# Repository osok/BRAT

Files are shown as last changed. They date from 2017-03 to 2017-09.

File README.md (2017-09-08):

Table of Contents

- [Description](#description)
- [Key components](#key-components)
- [Schematics](#schematics)
- [Board Fabrication](#board-fabrication)
- [Parts list](#parts-list)
- [How to build the Board](#how-to-build-the-board)
- [Where to buy](#where-to-buy)
- [References](#references)
- [BRAT-GUI](#brat-gui)
- [How to use](#how-to-use)

# Description
BRAT or Badge Reader Active Tap, allows you to either install this implant into an HID Prox or iClass 
Reader inline between the reader and server.  It captures the bits from the Data0 and Data1 line and 
decodes the Wiegand protocol.  It stores the value on its file system and writes the bits back out to the 
server.

The Device has a built in Access Point and web server.  You can connect to the Access Point with and 
device such as a smart phone or computer.  You can interact with the device through its web page.  The 
default address is http://192.168.4.1/view. This provides list of previous cards that have been used on 
the reader.

The data stored is

* Card Hex	
* Facility Code	
* Card Number	
* Raw Bits

The Card Hex is a URL link to replay the card to the reader.

Optionally you can connect the BRAT-GUI on the BRAT-RPi device, which is designed to allow printing of 
the card with a proxmark3.

# Key components
The BRAT implant is built using the node mcu V 0.9.  The Node MCU leverages the ESP 8266 SoC to provide
a WiFi Access Point, 1 MB code and 3 MB Flash for storage, two interrupts and a number of GPIO pins.

The node mcu provides a 5V regulator and programming circuits for the ESP 8266 12. 

The AP default name iPhone-BRAT, which can be changed at compile time.
 
On the BRAT there is a 3V3 to 5V logic converter.  This jumps the 3V3 logic signal that is put out by the 
ESP, to 5V which is required to drive the signal to the server.
There is a 5V Regulator that takes the line power from the server to the reader, which is between 12V 
and 24V and drops it to 5V.
There are two 10 uF capacitors to smooth the power out.
The main board must be fabricated, see below for more information on that. 

# Schematics
I used Eagle CAD to design the circuit and board.
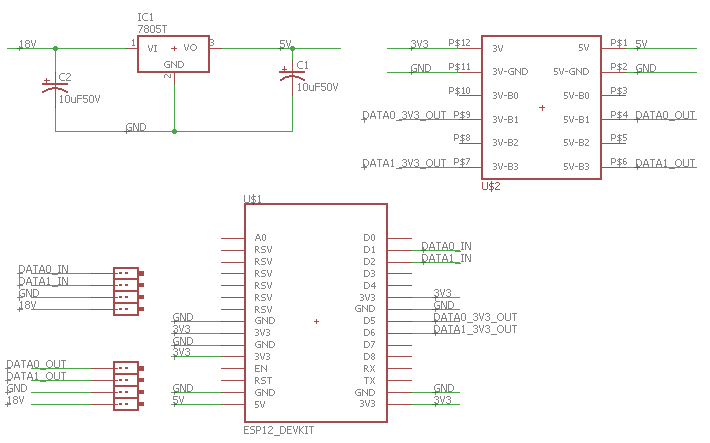
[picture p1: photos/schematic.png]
 

# Board Fabrication
When I fabricate my final boards I use [OSH Park](http://www.oshpark.com).  You will have to purchase 
three boards minimum for a total cost of $21.85 USD.

Front:<br>
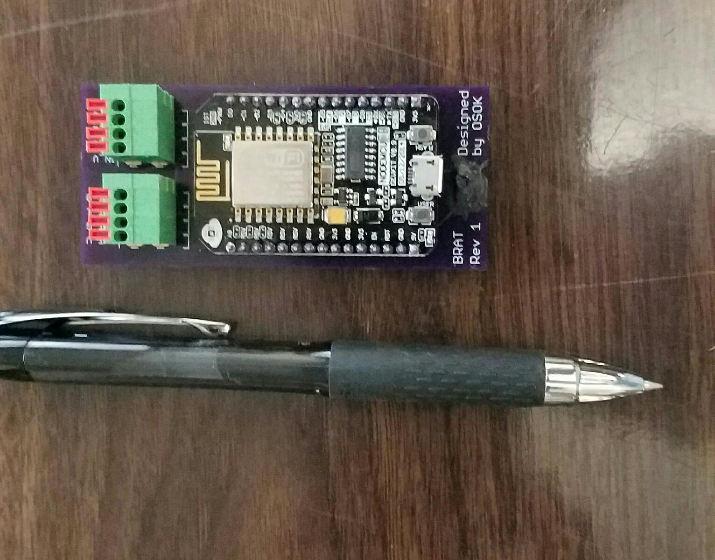
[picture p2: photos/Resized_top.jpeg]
 

Back:<br>
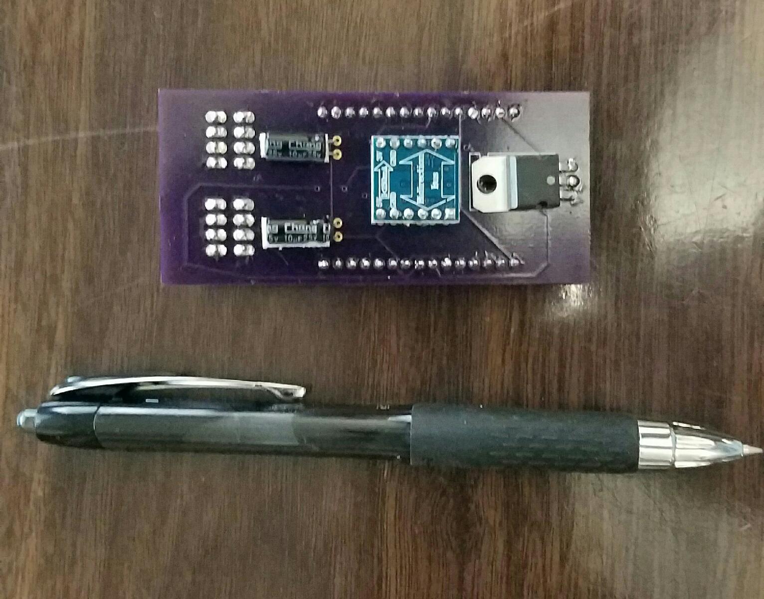
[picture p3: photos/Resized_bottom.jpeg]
 

# Parts list
So the cost individual cost is ~$24, depends on quantity and shipping.
* Node MCU $9
* Capacitors $1
* Level Converter $2
* Connectors $4
* Board $8

There are a number of different Logic converters out there.  Some simply move where the V_high/GND and V_low/GND are located, which makes them not compatable with this board, and others simply dont respond as they should.  Below are some examples:

 

I have found that even if you pay close attention to the ads on amazon and eBay, an only order the ones witht he double arrow on the back, some times they still send you other boards.

If you are only going to use this witht he Tastic, then you can forgo the Logic Level Converter.  Looking att he back side of the BRAT card solder the data out pins from the 3.3v side to straight across to the 5V side.  Don't solder the top pin one is 3V3 nd the other is 5V. That would be bad.  But 4th pin down and the bottom (6th Pin down) on the left solder a wire to the coresponding pin on the other side.   Left 4th pin to right 4th pin, and Left 6th pin to right 6th pin.   

# How to build the Board

https://youtu.be/rFhIB0w98co

# Where to buy
* I used some quick release connectors which can be ordered at: 
https://www.pololu.com/product/2427.
* The node mcu can be ordered from eBay or amazon: https://www.amazon.com/Industry-Park-NodeMcu-Internet-Development/dp/B01MG1LEU2/
* There are 2 Electrolytic Capacitors of 10 uF and at least 25V, I'll be using 50V. I have these as part of a 
larger kit.
* The voltage regulator is a LM7805.  I picked up about 20 of them from eBay.
* The level converter can be found on amazon: https://www.amazon.com/gp/product/B0148BLZGE/
* Board : 

# References
There are sections of the code that were orginally developed by Francis Brown of Bishop Fox for the [Tastic RFID Thief]( 
https://www.bishopfox.com/resources/tools/rfid-hacking/attack-tools/).  The BRAT works great in the 
Tastic RFID Thief.  This adds the capability for the user to monitor the badges acquired and for others to 
use the BRAT-GUI and BRAT-RPi to write badges as the attacker collects them.

# BRAT-GUI
The BRAT GUI is a Raspberry Pi with touch screen and ProxMark, for full life cycle badge cloning.  Use the BRAT in the Tastic
and the BRAT GUI to print badges on the fly.  

https://github.com/osok/BRAT/tree/master/BRAT-RPi-3D

# How to use

Once the BRAT is installed and powered on, you can connect to the AP.  The SSID can be modified before the source is compiled and loaded.  The password is also confgurable.  Based on what SSID / Password you used when compiling the source, will determine how to connect.

Once your mobile device is connected, you can use a browser to visit: http://192.168.4.2/view

You'll see the hex code with a link, Facility Code, Badge ID, and the raw bits.

Clicking the link with the hex code for a badge will replay the bits on the wire.  
So if this is installed as an implant you can replay cards that have been used since the implant was installed.

If the the device is being used witht he Tastic, use the BRAT-GUI to grab the card data from the BRAT and create clones in realtime.

# License

Creative Commons Attribution 3.0 United States
https://creativecommons.org/licenses/by/3.0/us/

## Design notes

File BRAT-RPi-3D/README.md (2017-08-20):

# Description

This box works great with  
* RPI 3 : https://www.adafruit.com/product/3055
* Pi foundation Display 7" Touch screen ($79): https://www.adafruit.com/product/2718
* Proxmark3 Easy ($88): https://www.ebay.com/i/262955750782?chn=ps&dispItem=1
* If you do not have a 3D printer all three parts costs about $80 - $120 on 3D hubs : https://www.3dhubs.com/ 
* Battery Pack ($39) : http://www.bestbuy.com/site/mycharge-razormax-portable-power-bank-black/6330174.p?skuId=6330174 :  I took it out of the case.  Using this style battery means longer life and easy to recharge.

See [RPI-GUI](https://github.com/osok/BRAT/tree/master/BRAT-GUI) for instructions on loading the software including the Ubuntu Mate.

# Assembly

TODO : Create video 

# License

Creative Commons Attribution 3.0 United States
https://creativecommons.org/licenses/by/3.0/us/

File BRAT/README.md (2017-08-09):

# Arduino Setup

Review instructions here for how to add the ESP 8266 boards to the Arduino IDE: https://github.com/esp8266/Arduino

# Config.h
Change the name of Config-Example.h to Config.h

You may want to pdate the SSID and the password for te Access Point so that others cannot connect as easily.  

# How to install software

Youtube video: https://youtu.be/guUEqy8e27w

Notes from the video
 
> You will need to code the GitHub Repo.
> https://github.com/osok/BRAT
> 
> In order to compile this You will need Ardunio IDE Installed.
> 
> Next you will need to install the NodeMCU Board.
> 
> Once you add the ESP 8266 board : http://arduino.esp8266.com/stable/package_esp8266com_index.json
> 
> Then restart the IDE.
> 
> Then goto tools > Boards > Board Manager and install
> 
> Then Select the Generic ESP8266
> 
> Then change to the Flash size to 4M (1M)
> 
> Then plug your BRAT Into the micro sd, selectt he port.  
> Press and hold the flash button while you plug the cable in.
> After 5 seconds you can release the button, it is now ready to be programmed.
>  
> Then you need to copy the Config-Example.h to Config.h
> In the Config.h Change the SSID and the password.
> 
> Then save and upload.  It will compile first.
> Then upload.
> Then success!!!

# License

Creative Commons Attribution 3.0 United States
https://creativecommons.org/licenses/by/3.0/us/

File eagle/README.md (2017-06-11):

Fabrication can be done at OSHPark : https://www.oshpark.com/

Link to the board on OSHPark : https://www.oshpark.com/shared_projects/jjDDSjZS

Link to Order the board : 


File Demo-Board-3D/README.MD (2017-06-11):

I used these to construct the demo board.
Mounting Clamps for 
* the BRAT
* Tastic control board 
* LCD Screen

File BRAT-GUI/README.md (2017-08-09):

# Description
BRAT-GUI is used on the BRAT-RPi to read the list of Hex Card values from the BRAT.  It is a java application cmpiled into a self executing JAR 

# Building the BRAT-GUI and BRAT-RPi

## BRAT-RPi

It's easiest to connect the RPi to a keyboard and mouse, while doing the set up.  You can use a HDMI monitor or the 7" Touch screen.

1. Install Ubunutu Mate : Follow instructions here https://ubuntu-mate.org/
2. Update the Ubuntu
```
sudo apt-get update
sudo apt-get upgrade
```
3. Install Proxmark3 for Ubuntu : Follow instructions here  https://github.com/Proxmark/proxmark3/wiki/Ubuntu-Linux
4. Install Java 8 to Ubuntu
```
sudo apt-get install openjdk-8-jdk
```

## BRAT-GUI
1. Download the BRAT-GUI.jar : https://github.com/osok/BRAT/tree/master/BRAT-GUI/dist
2. Download run.sh from the dist directory and place it in the same directory as the BRAT-GUI.jar
3. change the permissions on the run.sh file
```
chmod 700 run.sh
```
4. Download the lua script write_hid.lua and place it in the proxmark3/client/scripts directory : https://github.com/osok/BRAT/tree/master/proxmark3-scripts

# Operation

1. with the BRAT turned running
2. turn on the BRAT-GUI
3. open a terminal window and run proxmark client
```
sudo ./promark3 /dev/ttyACM0
```
4. run the run.sh
5. if you changed the IP address of the ESP (you would know it if you did), you can configure the Server IP in the configuration screen.
6. Press the Read Hex Codes
7. Select a Hex code to write_hid
8. Press write Hex Codes
9. Press the copy button
10. make sure there isa T5557 card in the card slot on the BRAT-RPi case
11. copy the contents of te clip board into the proxmark client terminal and hit enter

That's it.

# License

Creative Commons Attribution 3.0 United States
https://creativecommons.org/licenses/by/3.0/us/

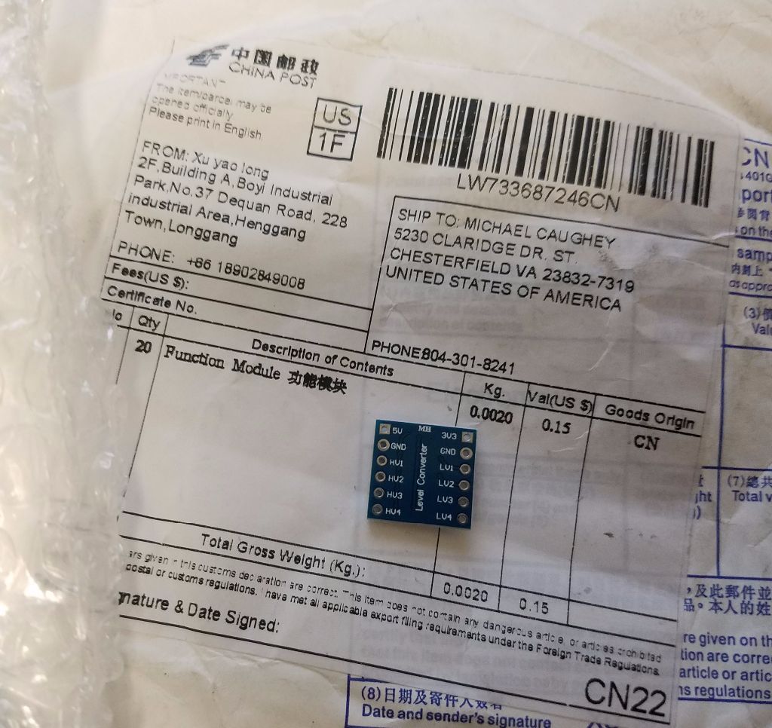
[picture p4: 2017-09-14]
photos/RtnDownloadFile.png

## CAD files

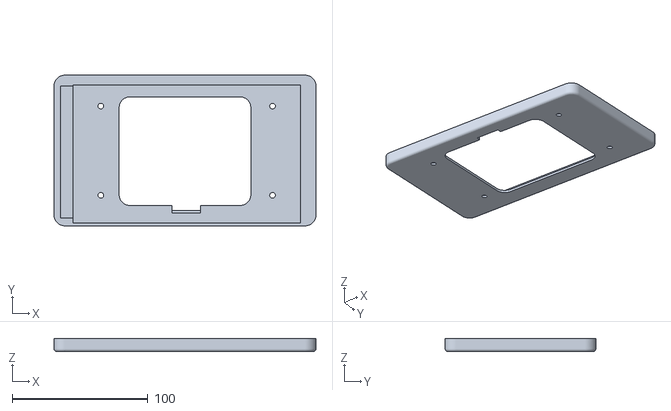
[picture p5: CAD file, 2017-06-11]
BRAT-RPi-3D/front.stl
193.0 x 111.0 x 9.60

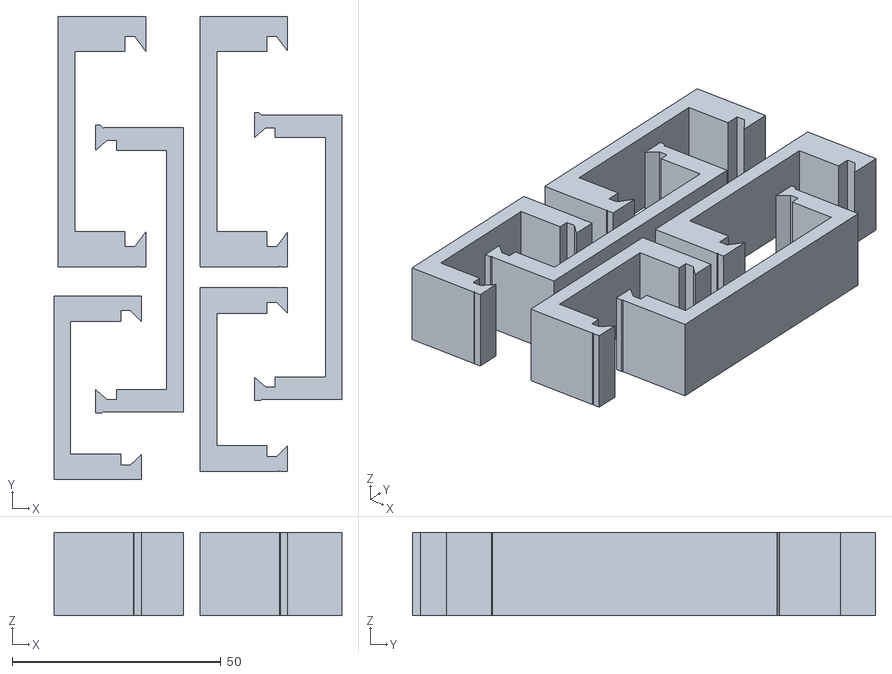
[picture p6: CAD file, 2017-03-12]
Demo-Board-3D/clamps.stl
69.0 x 111.0 x 20.0

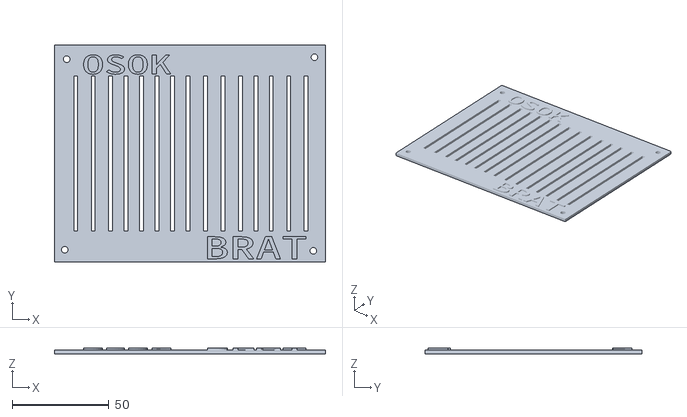
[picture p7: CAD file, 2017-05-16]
BRAT-RPi-3D/lid.stl
140.0 x 112.0 x 3.00

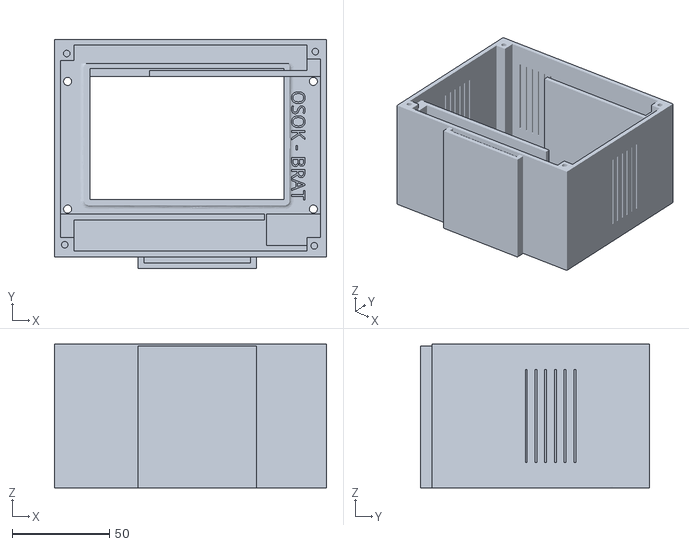
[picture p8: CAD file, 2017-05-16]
BRAT-RPi-3D/case.stl
140.0 x 118.0 x 74.0

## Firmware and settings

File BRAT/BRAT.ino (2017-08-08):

/**
 * BRAT.ino - Badge Reader Active Tap - is designed to
 *                connect to the Data0 & Data1 lines inside of a Wiegand
 *                based card reader.  It will store the card data on the 
 *                file system of an ESP8266-12.  The device sets up
 *                an Access Point that once connected to, presents
 *                a web page.  This web page shows card data info, and allows
 *                replay directly into the card reader.  A proxmark device
 *                can be used to program the card data onto a new card.
 *                The web server also provides a page of Hex vaules used
 *                by the BRAT RPi app. 
 *                
 * When I orginally set out to bypass the HID Prox devices, I did a lot of research        
 * I came along the Tastic RFID Reader by Bishop Fox, 
 * https://www.bishopfox.com/resources/tools/rfid-hacking/attack-tools/
 * After building a Tastic Reader I got the   idea that I could some how wirelessly 
 * send the card data to someon that could  then wirte a card for immediate use.
 * 
 * The portions of this code that read the signal from the line 
 * and decode the bits into FC and Card Num are the same
 * as what was coded in the Tastic thief.
 * 
 * The follwoing code is orginal to the BRAT
 *   - AP configuration
 *   - Web Server
 *   - Writing to another pair of pins are all orgiinal
 *   - the Trace logic for debugging
 *             
 * Created by osok
 * github https://github.com/osok/BRAT
 */


#include "Config.h"
#include <string.h>
#include <ESP8266WiFi.h>
#include <WiFiClient.h> 
#include <ESP8266WebServer.h>
#include <FS.h>
//#include <ArduinoOTA.h>

#define HOSTNAME "ESP8266-OTA-"

ESP8266WebServer server(80);

#define MAX_BITS 100                 // max number of bits 
#define WEIGAND_WAIT_TIME  3000      // time to wait for another weigand pulse.  


char* dataFile = "cards.htm"; // file to save card ids to
char* hexFile = "card-hex.htm"; // only the card hex is written to this file, one per line

unsigned char databits[MAX_BITS];    // stores all of the data bits
volatile unsigned int bitCount = 0;
unsigned char flagDone;          // goes low when data is currently being captured
unsigned int weigand_counter;        // countdown until we assume there are no more bits

volatile unsigned long facilityCode=0;        // decoded facility code
volatile unsigned long cardCode=0;            // decoded card code

// Breaking up card value into 2 chunks to create 10 char HEX value
volatile unsigned long bitHolder1 = 0;
volatile unsigned long bitHolder2 = 0;
volatile unsigned long cardChunk1 = 0;
volatile unsigned long cardChunk2 = 0;


#define DATA0_IN 5
#define DATA1_IN 4
#define DATA0_OUT 14
#define DATA1_OUT 12

/**
 * These variables are for the writing of the 
 * Bits to the bade reader 
 */
////These were based on timming from ebuging code
//#define SHORT_TIME 7  // 50 microseconds
////#define LONG_TIME 166 // 1 millisecond
//#define LONG_TIME 151 // 1 millisecond (minus overhead for wire writes)
//
// These are based on timing as seen by a logic analyzer
#define SHORT_TIME 655  // 50 microseconds
#define LONG_TIME 27146 // 1 millisecond (Takes into account over head other than the delay loop)
//#define LONG_TIME 16000 // 

int bitcnt1;
int bitcnt2;

unsigned long startTime;
unsigned long shortTime[80];
unsigned long longTime[80];
boolean isAOne[80];
boolean bitUsed[80];
int bitCountToWrite;
unsigned long endTime;


boolean isWriting = false;

///////////////////////////////////////////////////////
// Process interrupts

// interrupt that happens when INTO goes low (0 bit)
//[Copied from the Tastic RFID Thief]
void ISR_INT0()
{
 if(!isWriting){
//  Serial.print("0");
    bitCount++;
    flagDone = 0;
    
    if(bitCount < 23) {
        bitHolder1 = bitHolder1 << 1;
        bitcnt1++;
    }
    else {
        bitHolder2 = bitHolder2 << 1;
        bitcnt2++;
    }
      
    weigand_counter = WEIGAND_WAIT_TIME;  
 }
}

// interrupt that happens when INT1 goes low (1 bit)
//[Copied from the Tastic RFID Thief]
void ISR_INT1()
{
  if(!isWriting){
  //  Serial.print("1");
    databits[bitCount] = 1;
    bitCount++;
    flagDone = 0;
    
     if(bitCount < 23) {
        bitHolder1 = bitHolder1 << 1;
        bitHolder1 |= 1;
        bitcnt1++;
     }
     else {
       bitHolder2 = bitHolder2 << 1;
       bitHolder2 |= 1;
        bitcnt2++;
     }
    
    weigand_counter = WEIGAND_WAIT_TIME;  
  }
}

String getContentType(String filename){
  if(server.hasArg("download")) return "application/octet-stream";
  else if(filename.endsWith(".htm")) return "text/html";
  else if(filename.endsWith(".html")) return "text/html";
  else if(filename.endsWith(".css")) return "text/css";
  else if(filename.endsWith(".js")) return "application/javascript";
  else if(filename.endsWith(".png")) return "image/png";
  else if(filename.endsWith(".gif")) return "image/gif";
  else if(filename.endsWith(".jpg")) return "image/jpeg";
  else if(filename.endsWith(".ico")) return "image/x-icon";
  else if(filename.endsWith(".xml")) return "text/xml";
  else if(filename.endsWith(".pdf")) return "application/x-pdf";
  else if(filename.endsWith(".zip")) return "application/x-zip";
  else if(filename.endsWith(".gz")) return "application/x-gzip";
  return "text/plain";
}

bool handleFileRead(String path){
  Serial.println("handleFileRead: " + path);
  if(path.endsWith("/")) path += "index.htm";
  String contentType = getContentType(path);
  String pathWithGz = path + ".gz";
  if(SPIFFS.exists(pathWithGz) || SPIFFS.exists(path)){
    if(SPIFFS.exists(pathWithGz))
      path += ".gz";
    File file = SPIFFS.open(path, "r");
    size_t sent = server.streamFile(file, contentType);
    file.close();
    return true;
  }
  return false;
}

void handleCard() {
  handleFileRead(dataFile);
}
void handleCardHex() {
  handleFileRead(hexFile);
}


void handleClear() {
  SPIFFS.remove(dataFile);
  SPIFFS.remove(hexFile);
  server.send(200, "text/html", "<html><body>All Clear</body></html>");
}

void handleAccess() {
  unsigned long bitbuf1 = atol(server.arg("byte1").c_str());
  unsigned long  bitbuf2 = atol(server.arg("byte2").c_str());
  int bCnt1 = atol(server.arg("bitcnt1").c_str());
  int bCnt2 = atol(server.arg("bitcnt2").c_str());
  Serial.print("byte1=");
  Serial.println(bitbuf1);
  Serial.print("byte2=");
  Serial.println(bitbuf2);
  Serial.print("bits1=");
  Serial.println(bitbuf1,BIN);
  Serial.print("bits2=");
  Serial.println(bitbuf2, BIN);
  Serial.print("bCnt1=");
  Serial.println(bCnt1);
  Serial.print("bCnt2=");
  Serial.println(bCnt2);

   
  sendBadgeBits(bitbuf1,bitbuf2,bCnt1,bCnt2 );
  //printTimes();
  handleView();
}

void handleView() {
  //This is seperate in order to add eventual formatting around the card page
  server.send(200, "text/html", "<html><body><iframe src=\"/card\" frameborder=\"0\" scrolling=\"no\" width=\"100%\" height=\"100%\"></html>");
}

void setupForRFIDRead(){
  
  pinMode(DATA0_IN, INPUT_PULLUP);     
  pinMode(DATA1_IN, INPUT_PULLUP);   
  delay(500);  
  attachInterrupt(digitalPinToInterrupt(DATA0_IN), ISR_INT0, FALLING);  
  attachInterrupt(digitalPinToInterrupt(DATA1_IN), ISR_INT1, FALLING);
  Serial.println("Ready to read...");
}


void setupForRFIDWrite(){
  pinMode(DATA0_OUT, OUTPUT);     
  pinMode(DATA1_OUT, OUTPUT);    
  digitalWrite(DATA0_OUT, HIGH);
  digitalWrite(DATA1_OUT, HIGH);
  delay(500);
  Serial.println("Ready to write...");
}

void setup() {

  Serial.begin(115200);
  setupForRFIDRead();
  setupForRFIDWrite();
  
  Serial.println();
  Serial.print("Chip ID: 0x");
  Serial.println(ESP.getChipId(), HEX);
  Serial.println();
  String hostname(HOSTNAME);
  hostname += String(ESP.getChipId(), HEX);
  WiFi.hostname(hostname);
  Serial.println("Hostname: " + hostname);
 
  Serial.print("Configuring AP...");

  if (!SPIFFS.begin())
  {
    Serial.println("Failed to mount file system");
    return;
  }

  WiFi.softAP(ssid, password);

  IPAddress myIP = WiFi.softAPIP();
  Serial.print("IP address: ");
  Serial.println(myIP);
  server.on("/clear", handleClear);
  server.on("/view", handleView);
  server.on("/card", handleCard);
  server.on("/hex", handleCardHex);
  server.on("/access", handleAccess);
  server.begin();
  Serial.println("server started");

//  ArduinoOTA.setHostname((const char *)hostname.c_str());
//  ArduinoOTA.begin();

  weigand_counter = WEIGAND_WAIT_TIME;

}

void loop() {
  server.handleClient();
  yield();
//  ArduinoOTA.handle();
//  yield();
  
  // This waits to make sure that there have been no more data pulses before processing data
  if (!flagDone) {

    
    if (--weigand_counter == 0)
      flagDone = 1;  
  }
  
  // if we have bits and we the weigand counter went out
  if (bitCount > 0 && flagDone) {
//    Serial.print("Bitcount 1 = ");
//    Serial.println(bitcnt1);
//    Serial.print("Bitcount 2 = ");
//    Serial.println(bitcnt2);
    
    unsigned char i;

    //Write bits to the wire first thing in order to reduce delay
    sendBadgeBits(bitHolder1,bitHolder2,bitcnt1,bitcnt2 );
    
    getCardValues();
    getCardNumAndSiteCode();
       
    printBits();
    writeDataToFS();

     // cleanup and get ready for the next card
     bitCount = 0; facilityCode = 0; cardCode = 0;
     bitHolder1 = 0; bitHolder2 = 0;
     cardChunk1 = 0; cardChunk2 = 0;
     
     for (i=0; i<MAX_BITS; i++) 
     {
       databits[i] = 0;
     }

     bitcnt1 = 0;
     bitcnt2 = 0;
  }  
}
void printBits(){
      Serial.print(bitCount);
      Serial.print(" bit card. ");
      Serial.print("FC = ");
      Serial.print(facilityCode);
      Serial.print(", CC = ");
      Serial.print(cardCode);
      Serial.print(", 44bit HEX = ");
      Serial.print(cardChunk1, HEX);
      Serial.println(cardChunk2, HEX);
      
  }

  ///////////////////////////////////////////////////////
// SETUP function  [Copied from the Tastic RFID Thief]
void getCardNumAndSiteCode()
{
     unsigned char i;
  
    // we will decode the bits differently depending on how many bits we have
    // see www.pagemac.com/azure/data_formats.php for more info
    // also specifically: https://www.brivo.com/support/card-calculator
    switch (bitCount) {

      
    ///////////////////////////////////////
    // standard 26 bit format
    // facility code = bits 2 to 9  
    case 26:
      for (i=1; i<9; i++)
      {
         facilityCode <<=1;
         facilityCode |= databits[i];
      }
      
      // card code = bits 10 to 23
      for (i=9; i<25; i++)
      {
         cardCode <<=1;
         cardCode |= databits[i];
      }
      break;

    ///////////////////////////////////////
    // 33 bit HID Generic    
    case 33:  
      for (i=1; i<8; i++)
      {
         facilityCode <<=1;
         facilityCode |= databits[i];
      }
      
      // card code
      for (i=8; i<32; i++)
      {
         cardCode <<=1;
         cardCode |= databits[i];
      }    
      break;

    ///////////////////////////////////////
    // 34 bit HID Generic 
    case 34:  
      for (i=1; i<17; i++)
      {
         facilityCode <<=1;
         facilityCode |= databits[i];
      }
      
      // card code
      for (i=17; i<33; i++)
      {
         cardCode <<=1;
         cardCode |= databits[i];
      }    
      break;
 
    ///////////////////////////////////////
    // 35 bit HID Corporate 1000 format
    // facility code = bits 2 to 14     
    case 35:  
      for (i=2; i<14; i++)
      {
         facilityCode <<=1;
         facilityCode |= databits[i];
      }
      
      // card code = bits 15 to 34
      for (i=14; i<34; i++)
      {
         cardCode <<=1;
         cardCode |= databits[i];
      }    
      break;

    }
    return;
  
}


//////////////////////////////////////
// Function to append the card value (bitHolder1 and bitHolder2) to the necessary array then tranlate that to
// the two chunks for the card value that will be output
// [Copied from the Tastic RFID Thief]
void getCardValues() {
  switch (bitCount) {
    case 26:
        // Example of full card value
        // |>   preamble   <| |>   Actual card value   <|
        // 000000100000000001 11 111000100000100100111000
        // |> write to chunk1 <| |>  write to chunk2   <|
        
       for(int i = 19; i >= 0; i--) {
          if(i == 13 || i == 2){
            bitWrite(cardChunk1, i, 1); // Write preamble 1's to the 13th and 2nd bits
          }
          else if(i > 2) {
            bitWrite(cardChunk1, i, 0); // Write preamble 0's to all other bits above 1
          }
          else {
            bitWrite(cardChunk1, i, bitRead(bitHolder1, i + 20)); // Write remaining bits to cardChunk1 from bitHolder1
          }
          if(i < 20) {
            bitWrite(cardChunk2, i + 4, bitRead(bitHolder1, i)); // Write the remaining bits of bitHolder1 to cardChunk2
          }
          if(i < 4) {
            bitWrite(cardChunk2, i, bitRead(bitHolder2, i)); // Write the remaining bit of cardChunk2 with bitHolder2 bits
          }
        }
        break;

    case 27:
       for(int i = 19; i >= 0; i--) {
          if(i == 13 || i == 3){
            bitWrite(cardChunk1, i, 1);
          }
          else if(i > 3) {
            bitWrite(cardChunk1, i, 0);
          }
          else {
            bitWrite(cardChunk1, i, bitRead(bitHolder1, i + 19));
          }
          if(i < 19) {
            bitWrite(cardChunk2, i + 5, bitRead(bitHolder1, i));
          }
          if(i < 5) {
            bitWrite(cardChunk2, i, bitRead(bitHolder2, i));
          }
        }
        break;

    case 28:
       for(int i = 19; i >= 0; i--) {
          if(i == 13 || i == 4){
            bitWrite(cardChunk1, i, 1);
          }
          else if(i > 4) {
            bitWrite(cardChunk1, i, 0);
          }
          else {
            bitWrite(cardChunk1, i, bitRead(bitHolder1, i + 18));
          }
          if(i < 18) {
            bitWrite(cardChunk2, i + 6, bitRead(bitHolder1, i));
          }
          if(i < 6) {
            bitWrite(cardChunk2, i, bitRead(bitHolder2, i));
          }
        }
        break;

    case 29:
       for(int i = 19; i >= 0; i--) {
          if(i == 13 || i == 5){
            bitWrite(cardChunk1, i, 1);
          }
          else if(i > 5) {
            bitWrite(cardChunk1, i, 0);
          }
          else {
            bitWrite(cardChunk1, i, bitRead(bitHolder1, i + 17));
          }
          if(i < 17) {
            bitWrite(cardChunk2, i + 7, bitRead(bitHolder1, i));
          }
          if(i < 7) {
            bitWrite(cardChunk2, i, bitRead(bitHolder2, i));
          }
        }
        break;

    case 30:
       for(int i = 19; i >= 0; i--) {
          if(i == 13 || i == 6){
            bitWrite(cardChunk1, i, 1);
          }
          else if(i > 6) {
            bitWrite(cardChunk1, i, 0);
          }
          else {
            bitWrite(cardChunk1, i, bitRead(bitHolder1, i + 16));
          }
          if(i < 16) {
            bitWrite(cardChunk2, i + 8, bitRead(bitHolder1, i));
          }
          if(i < 8) {
            bitWrite(cardChunk2, i, bitRead(bitHolder2, i));
          }
        }
        break;

    case 31:
       for(int i = 19; i >= 0; i--) {
          if(i == 13 || i == 7){
            bitWrite(cardChunk1, i, 1);
          }
          else if(i > 7) {
            bitWrite(cardChunk1, i, 0);
          }
          else {
            bitWrite(cardChunk1, i, bitRead(bitHolder1, i + 15));
          }
          if(i < 15) {
            bitWrite(cardChunk2, i + 9, bitRead(bitHolder1, i));
          }
          if(i < 9) {
            bitWrite(cardChunk2, i, bitRead(bitHolder2, i));
          }
        }
        break;

    case 32:
       for(int i = 19; i >= 0; i--) {
          if(i == 13 || i == 8){
            bitWrite(cardChunk1, i, 1);
          }
          else if(i > 8) {
            bitWrite(cardChunk1, i, 0);
          }
          else {
            bitWrite(cardChunk1, i, bitRead(bitHolder1, i + 14));
          }
          if(i < 14) {
            bitWrite(cardChunk2, i + 10, bitRead(bitHolder1, i));
          }
          if(i < 10) {
            bitWrite(cardChunk2, i, bitRead(bitHolder2, i));
          }
        }
        break;

    case 33:
       for(int i = 19; i >= 0; i--) {
          if(i == 13 || i == 9){
            bitWrite(cardChunk1, i, 1);
          }
          else if(i > 9) {
            bitWrite(cardChunk1, i, 0);
          }
          else {
            bitWrite(cardChunk1, i, bitRead(bitHolder1, i + 13));
          }
          if(i < 13) {
            bitWrite(cardChunk2, i + 11, bitRead(bitHolder1, i));
          }
          if(i < 11) {
            bitWrite(cardChunk2, i, bitRead(bitHolder2, i));
          }
        }
        break;

    case 34:
       for(int i = 19; i >= 0; i--) {
          if(i == 13 || i == 10){
            bitWrite(cardChunk1, i, 1);
          }
          else if(i > 10) {
            bitWrite(cardChunk1, i, 0);
          }
          else {
            bitWrite(cardChunk1, i, bitRead(bitHolder1, i + 12));
          }
          if(i < 12) {
            bitWrite(cardChunk2, i + 12, bitRead(bitHolder1, i));
          }
          if(i < 12) {
            bitWrite(cardChunk2, i, bitRead(bitHolder2, i));
          }
        }
        break;

    case 35:        
       for(int i = 19; i >= 0; i--) {
          if(i == 13 || i == 11){
            bitWrite(cardChunk1, i, 1);
          }
          else if(i > 11) {
            bitWrite(cardChunk1, i, 0);
          }
          else {
            bitWrite(cardChunk1, i, bitRead(bitHolder1, i + 11));
          }
          if(i < 11) {
            bitWrite(cardChunk2, i + 13, bitRead(bitHolder1, i));
          }
          if(i < 13) {
            bitWrite(cardChunk2, i, bitRead(bitHolder2, i));
          }
        }
        break;

    case 36:
       for(int i = 19; i >= 0; i--) {
          if(i == 13 || i == 12){
            bitWrite(cardChunk1, i, 1);
          }
          else if(i > 12) {
            bitWrite(cardChunk1, i, 0);
          }
          else {
            bitWrite(cardChunk1, i, bitRead(bitHolder1, i + 10));
          }
          if(i < 10) {
            bitWrite(cardChunk2, i + 14, bitRead(bitHolder1, i));
          }
          if(i < 14) {
            bitWrite(cardChunk2, i, bitRead(bitHolder2, i));
          }
        }
        break;

    case 37:
       for(int i = 19; i >= 0; i--) {
          if(i == 13){
            bitWrite(cardChunk1, i, 0);
          }
          else {
            bitWrite(cardChunk1, i, bitRead(bitHolder1, i + 9));
          }
          if(i < 9) {
            bitWrite(cardChunk2, i + 15, bitRead(bitHolder1, i));
          }
          if(i < 15) {
            bitWrite(cardChunk2, i, bitRead(bitHolder2, i));
          }
        }
        break;
  }
  return;
}

/**
 * Used to write the stored badge bits to the wire 
 */
void sendBadgeBits(unsigned long bits1,unsigned long bits2, int bCnt1, int bCnt2){
  isWriting = true;
  setupForRFIDWrite();
  startTime = ESP.getCycleCount(); 
  unsigned long test = 0;
  unsigned long shiftedBits;
  int adjustment;
  bitCountToWrite = 0;
  
//  Setting up the first set of bits
//  Serial.println(bits1, BIN);
 
  for(int i=bCnt1-1;i >= 0; i--){
    if(i>23 ){
      shiftedBits = bits1 >> 24;
      adjustment = 24;
    }else if(i>15 ){
      shiftedBits = bits1 >> 16;
      adjustment = 16;
    }else if(i>7 ){
      shiftedBits = bits1 >> 8;
      adjustment = 8;
    }else {
      shiftedBits = bits1;
      adjustment = 0;
    }
    
    bitCountToWrite++;
    bitUsed[i+bCnt2] = true;
    test = 0;
    test = 1UL << (i-adjustment);
//    Serial.print("adjustment = ");
//    Serial.println(adjustment);
//    Serial.print("Test = ");
//    Serial.println(test, BIN);
    isAOne[i+bCnt2] = (shiftedBits & test);
    
//    Serial.print("Index = ");
//    Serial.println((i+bCnt2));
//    Serial.print("Bit = ");
//    Serial.println(isAOne[i+bCnt2]?"1":"0");
  }

//  Setting up the second set of bits
  for(int i=bCnt2-1;i >= 0; i--){
     if(i>23 ){
      shiftedBits = bits2 >> 24;
      adjustment = 24;
    }else if(i>15 ){
      shiftedBits = bits2 >> 16;
      adjustment = 16;
    }else if(i>7 ){
      shiftedBits = bits2 >> 8;
      adjustment = 8;
    }else {
      shiftedBits = bits2;
      adjustment = 0;
    }
    
    bitCountToWrite++;
    bitUsed[i] = true;
    test = 0;
    test = 1UL << (i-adjustment);
//    Serial.print("adjustment = ");
//    Serial.println(adjustment);
//    Serial.print("Test = ");
//    Serial.println(test, BIN);
    isAOne[i] = (shiftedBits & test);
//    Serial.print("Index = ");
//    Serial.println(i);
//    Serial.print("Bit = ");
//    Serial.println(isAOne[i]?"1":"0");
  }


//  Serial.print("bitCountToWrite = ");
//  Serial.println(bitCountToWrite);

/**
 * This is where the pulses are sent out
 * pulse LOW on DATA0 represents a 0 bit
 * pulse LOW on DATA1 represents a 1 bit
 * The pulse is only 50 micro seconds
 * Then there the line is se high
 * and a pause of 1 millisecond.
 * Though testing i was determined that the 
 * loop between the two digitalWrites is exactly 
 * 50 microseconds.  The second loop takes into 
 * consideration all the over head and buffers
 * to provide a 1 millisecond pause. 
 */
  for(int i=bitCountToWrite-1; i>=0; i--){
    digitalWrite((isAOne[i] ?DATA1_OUT:DATA0_OUT), LOW);
    for(long a=0;a<SHORT_TIME;a++){
       ESP.getCycleCount();
    }
    digitalWrite((isAOne[i]?DATA1_OUT:DATA0_OUT), HIGH);
    shortTime[i] = ESP.getCycleCount();
    
    for(long a=0;a<LONG_TIME;a++){
       ESP.getCycleCount();
    }
    longTime[i] = ESP.getCycleCount();
  }


  endTime = ESP.getCycleCount();  
  Serial.println("");
 
  isWriting = false;
}
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

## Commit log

2017-02-05 update
    The code base can now write bits back out ot the reader. I'm currently
    working on the levels so that the eSP can write the correct voltage
    levels.
    [BRAT.ino]
2017-02-18 code works!
    Now I need to get the circuit designed.
2017-02-22 Board Prototype is done
    The board prototype is done. Had to make some minor code changes to
    support it. This model of the board should make it easy for people to
    build.
    [BRAT.brd]
2017-03-12 Initial Checkin
    Mounting clamps for the demo board
    [clamps.stl]
2017-03-12 compact
    Created a smaller footprint and removed a srtray object.
    [clamps.stl]
2017-03-12 resized the LCD clamp
    [clamps.stl]
2017-05-16 Raspberry Pi box
    Attaches to the back side of the 7" touch screen to encase the driver
    board, RPI, Battery pack and Proxmark3
    [case.stl, lid.stl]
2017-05-16 Updated RPI Box
    Added airflow vents, and two compartments for proxmark3 and battery.
    [case.stl, lid.stl]
2017-06-11 renames directories
    [case.stl, clamps.stl, front.stl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]
